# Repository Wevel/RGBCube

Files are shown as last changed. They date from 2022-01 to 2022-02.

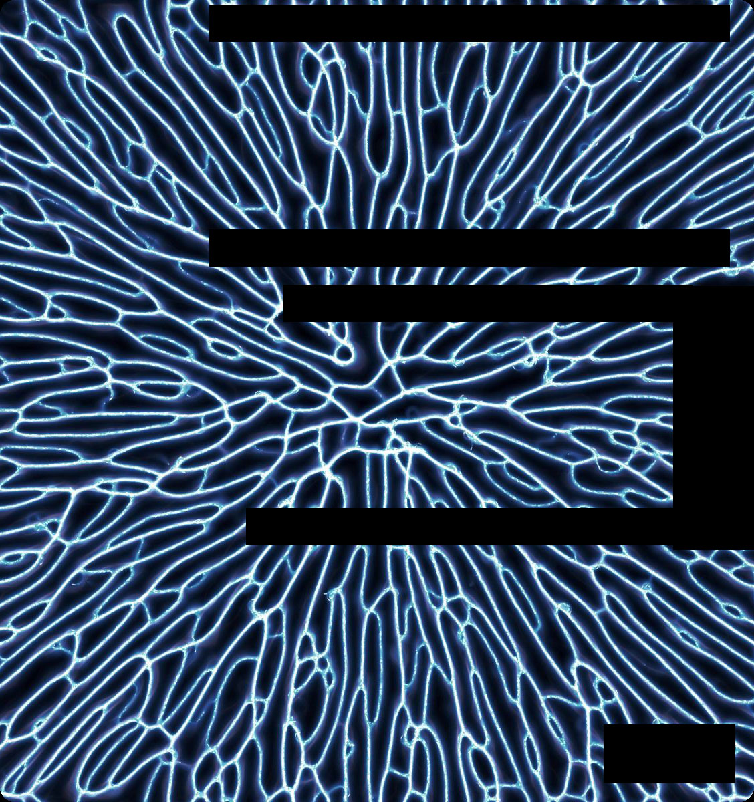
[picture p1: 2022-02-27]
Hardware/Controller/r0.1/RGBCubeController/SilkscreenPatterns/slimeMold-0.jpg

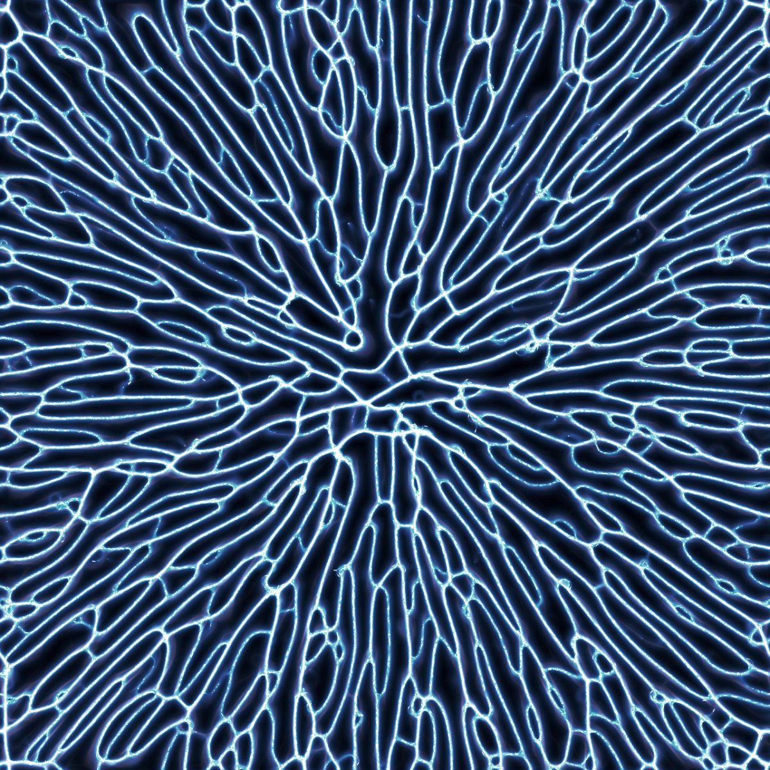
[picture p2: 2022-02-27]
Hardware/Controller/r0.1/RGBCubeController/SilkscreenPatterns/ch3_1801_slimeMold_04-1200x1200-.jpg

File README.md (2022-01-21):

# RGBCube
Project aiming to create a small led cube similar to that of [Greg Davill](https://gregdavill.com/blog/2020/6/13/miniature-3456x-led-cube). This will likely use the same [LED panels](https://github.com/gregdavill/GlassUnicorn/tree/master/hardware/panel_r0.1), but will require a new control board to account for what components are available.

## Control Board
* Change MCU to ESP32 module so as to add wifi connectivity and simplify PCB
* Change FPGA to use one of the following:
	* [Teensy 4.0](https://www.pjrc.com/store/teensy40.html): Not an FPGA, but probably still powerful enough
	* [iCEBreaker Bitsy](https://1bitsquared.com/products/icebreaker-bitsy): Not currently available, but uses the same footprint as the Teensy 4.0, so could be a future upgrade
	* [UPduino v3.1](https://tinyvision.ai/products/upduino-v3-0): May be too long
* Change IMU (Hopefully to the BNO055 if it is ever available again)

## Led Panel
This will likely use the same [LED panels](https://github.com/gregdavill/GlassUnicorn/tree/master/hardware/panel_r0.1) as Greg Davill.

## Frame
May try to 3d print something.

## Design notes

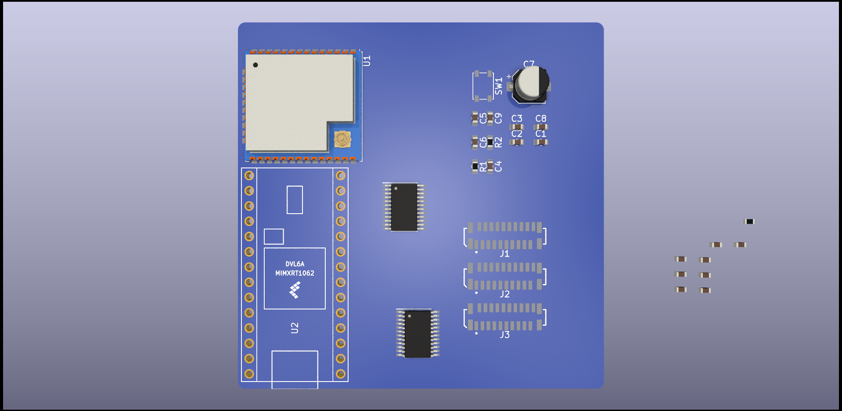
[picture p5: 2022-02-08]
Hardware/Controller/r0.1/RGBCubeController/RGBCubeController.png

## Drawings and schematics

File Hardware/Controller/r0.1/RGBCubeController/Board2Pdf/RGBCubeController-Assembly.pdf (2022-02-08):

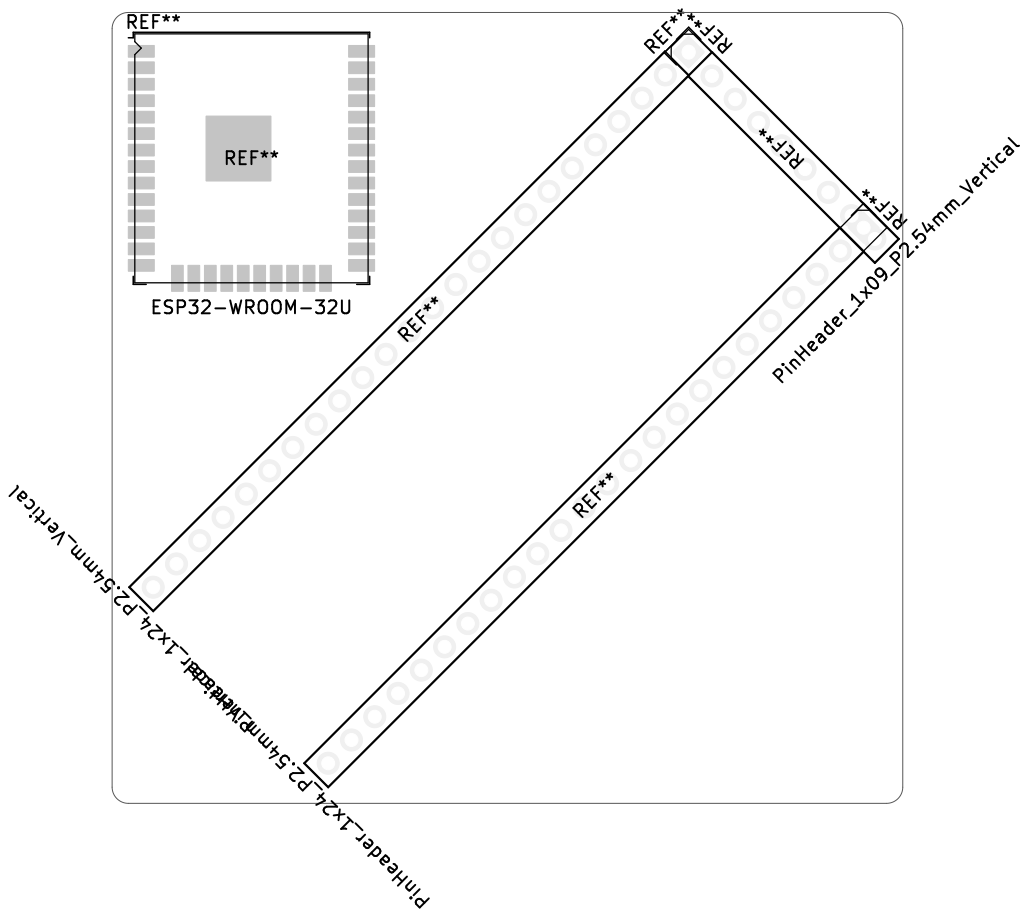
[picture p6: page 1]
REF**; REF** REF**; REF** 1 2 3 4 5 6; D Date: KiCad E.D.A. kicad (6.99.0-459-g8fe16690b7) Size: A4; Rev:; Id: 1/1 Title:; File: RGBCubeController.kicad_pcb; Sheet: Assembly; ESP32-WROOM-32U; PinHeader_1x09_P2.54mm_Vertical REF**; PinHeader_1x24_P2.54mm_Vertical

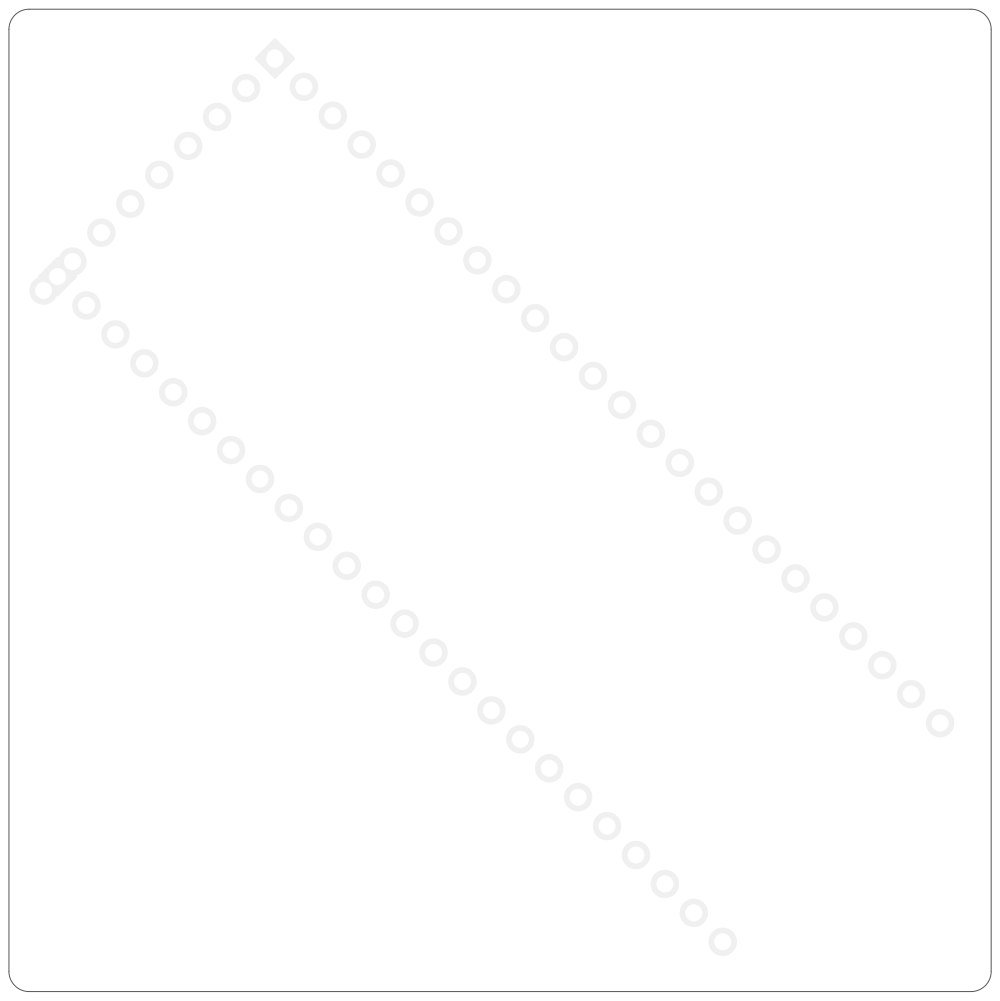
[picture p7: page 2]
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

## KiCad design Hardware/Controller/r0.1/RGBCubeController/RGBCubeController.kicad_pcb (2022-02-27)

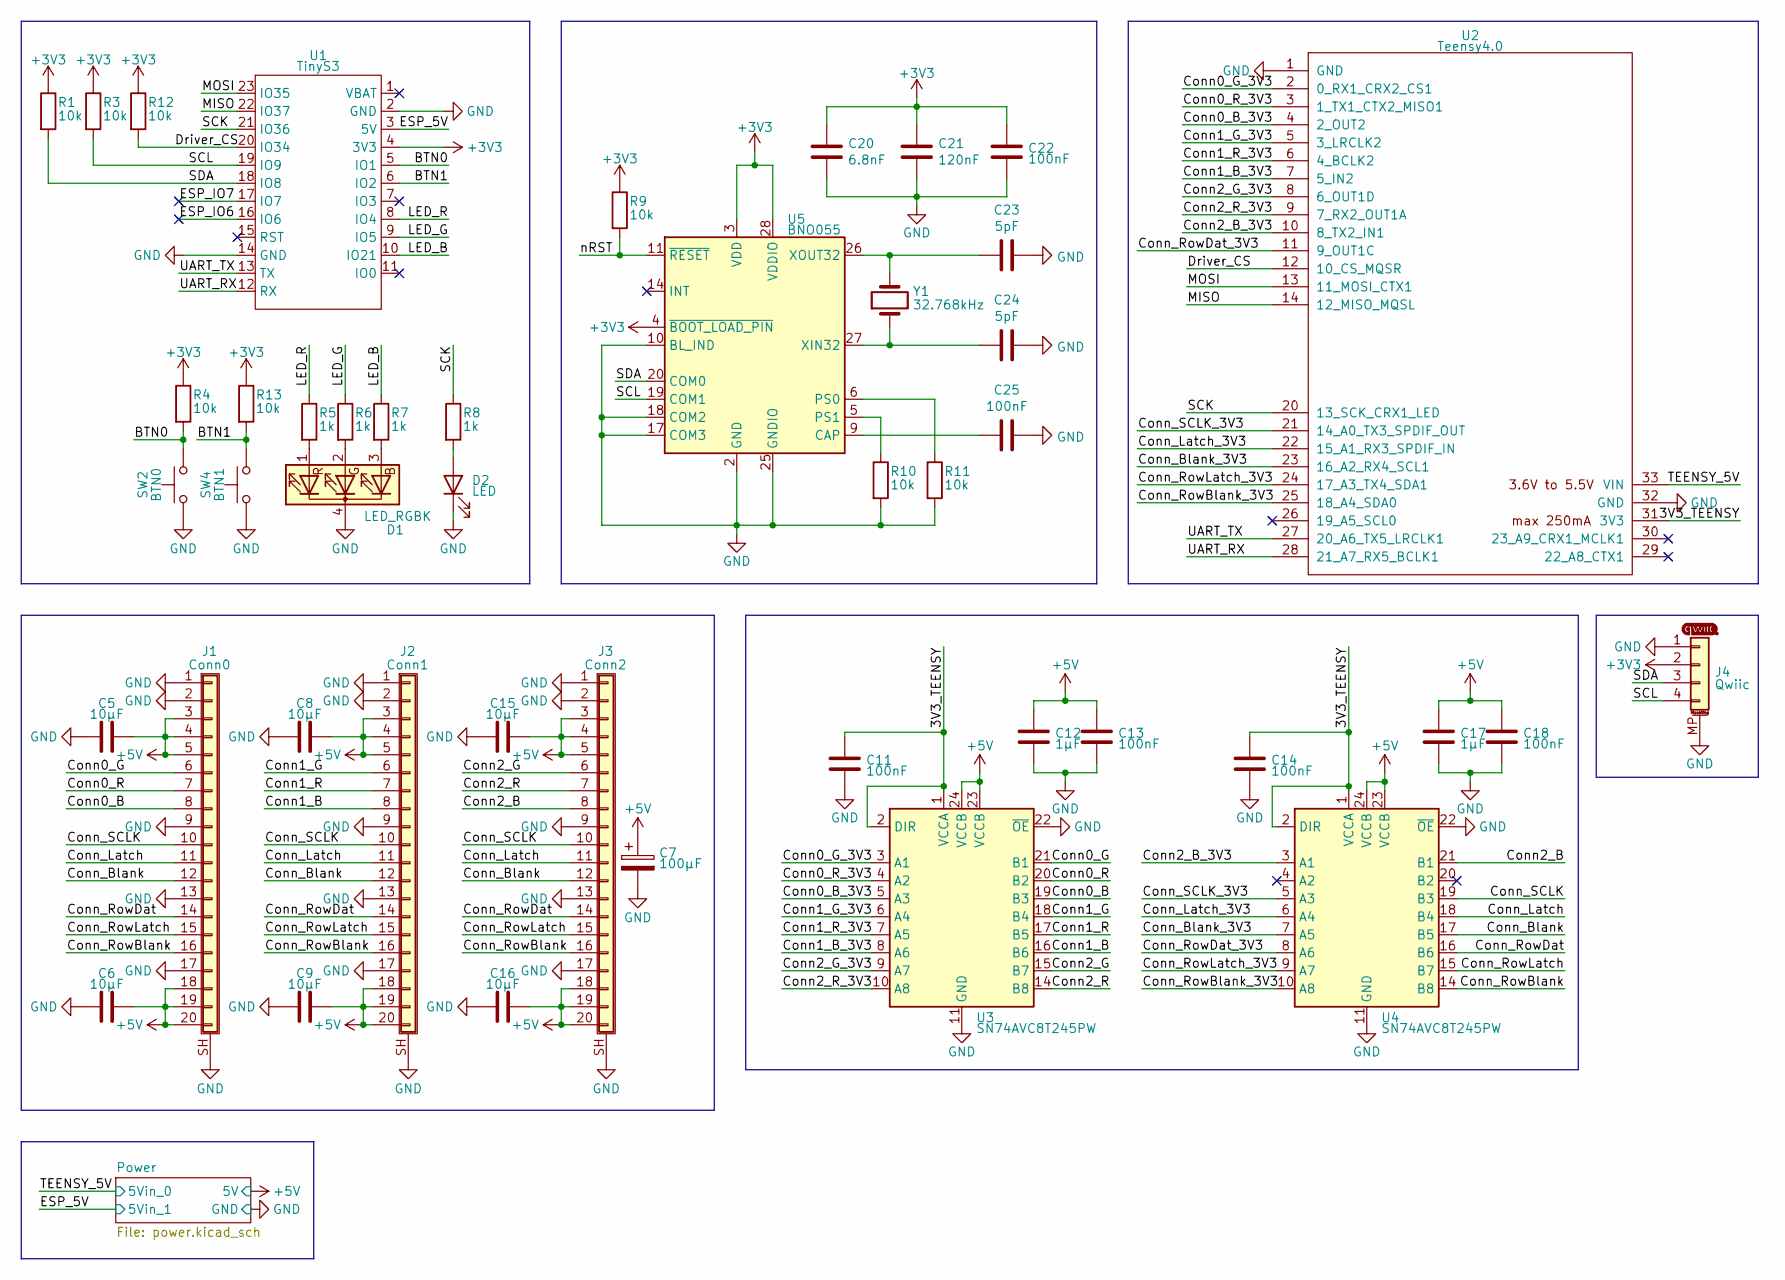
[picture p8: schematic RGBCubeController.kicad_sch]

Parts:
C5, C6, C8, C9, C15, C16: 10μF; C_0603_1608Metric
C7: 100μF; CP_Elec_5x3.9
C11, C13, C14, C18, C22, C25: 100nF; C_0603_1608Metric
C12, C17: 1μF; C_0603_1608Metric
C20: 6.8nF; C_0603_1608Metric
C21: 120nF; C_0603_1608Metric
C23, C24: 5pF; C_0402_1005Metric
D1: LED_RGBK; LED_Kingbright_AAA3528ESGCT
D2: LED; LED_0603_1608Metric
G1: LOGO; Qwiic
J1: Conn0; HRS_FH12-20S-0.5SVA(54)
J2: Conn1; HRS_FH12-20S-0.5SVA(54)
J3: Conn2; HRS_FH12-20S-0.5SVA(54)
J4: Qwiic; JST_SH_SM04B-SRSS-TB_1x04-1MP_P1.00mm_Horizontal
R1, R3, R4, R9, R10, R11, R12, R13: 10k; R_0603_1608Metric
R5, R6, R7, R8: 1k; R_0603_1608Metric
SW2: BTN0; PTS841_GKP
SW4: BTN1; PTS841_GKP
U1: TinyS3
U2: Teensy4.0; Teensy40_EdgesOnly
U3, U4: SN74AVC8T245PW; TSSOP-24_4.4x7.8mm_P0.65mm
U5: BNO055; LGA-28_5.2x3.8mm_P0.5mm
Y1: 32.768kHz; Crystal_SMD_3215-2Pin_3.2x1.5mm

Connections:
+3V3: C20.1, C21.1, C22.1, J4.2, R1.1, R3.1, R4.1, R9.1, R12.1, R13.1, U1.4 (3V3), U5.3 (VDD), U5.4 (~BOOT_LOAD_PIN), U5.28 (VDDIO)
+5V: C5.2, C6.2, C7.1, C8.2, C9.2, C12.2, C13.1, C15.2, C16.2, C17.2, C18.1, J1.3, J1.4, J1.5, J1.18, J1.19, J1.20, J2.3, J2.4, J2.5, J2.18, J2.19, J2.20, J3.3, J3.4, J3.5, J3.18, J3.19, J3.20, U3.23 (VCCB), U3.24 (VCCB), U4.23 (VCCB), U4.24 (VCCB); also elsewhere on the board
/3V3_TEENSY: C11.1, C14.1, U2.31 (3V3), U3.1 (VCCA), U3.2 (DIR), U4.1 (VCCA), U4.2 (DIR)
/BTN0: R4.2, SW2.2, U1.5 (IO1)
/BTN1: R13.2, SW4.2, U1.6 (IO2)
/Conn0_B: J1.8, U3.19 (B3)
/Conn0_B_3V3: U2.4 (2_OUT2), U3.5 (A3)
/Conn0_G: J1.6, U3.21 (B1)
/Conn0_G_3V3: U2.2 (0_RX1_CRX2_CS1), U3.3 (A1)
/Conn0_R: J1.7, U3.20 (B2)
/Conn0_R_3V3: U2.3 (1_TX1_CTX2_MISO1), U3.4 (A2)
/Conn1_B: J2.8, U3.16 (B6)
/Conn1_B_3V3: U2.7 (5_IN2), U3.8 (A6)
/Conn1_G: J2.6, U3.18 (B4)
/Conn1_G_3V3: U2.5 (3_LRCLK2), U3.6 (A4)
/Conn1_R: J2.7, U3.17 (B5)
/Conn1_R_3V3: U2.6 (4_BCLK2), U3.7 (A5)
/Conn2_B: J3.8, U4.21 (B1)
/Conn2_B_3V3: U2.10 (8_TX2_IN1), U4.3 (A1)
/Conn2_G: J3.6, U3.15 (B7)
/Conn2_G_3V3: U2.8 (6_OUT1D), U3.9 (A7)
/Conn2_R: J3.7, U3.14 (B8)
/Conn2_R_3V3: U2.9 (7_RX2_OUT1A), U3.10 (A8)
/Conn_Blank: J1.12, J2.12, J3.12, U4.17 (B5)
/Conn_Blank_3V3: U2.23 (16_A2_RX4_SCL1), U4.7 (A5)
/Conn_Latch: J1.11, J2.11, J3.11, U4.18 (B4)
/Conn_Latch_3V3: U2.22 (15_A1_RX3_SPDIF_IN), U4.6 (A4)
/Conn_RowBlank: J1.16, J2.16, J3.16, U4.14 (B8)
/Conn_RowBlank_3V3: U2.25 (18_A4_SDA0), U4.10 (A8)
/Conn_RowDat: J1.14, J2.14, J3.14, U4.16 (B6)
/Conn_RowDat_3V3: U2.11 (9_OUT1C), U4.8 (A6)
/Conn_RowLatch: J1.15, J2.15, J3.15, U4.15 (B7)
/Conn_RowLatch_3V3: U2.24 (17_A3_TX4_SDA1), U4.9 (A7)
/Conn_SCLK: J1.10, J2.10, J3.10, U4.19 (B3)
/Conn_SCLK_3V3: U2.21 (14_A0_TX3_SPDIF_OUT), U4.5 (A3)
/Driver_CS: R12.2, U1.20 (IO34), U2.12 (10_CS_MQSR)
/ESP_5V: U1.3 (5V); also elsewhere on the board
/ESP_IO6: U1.16 (IO6)
/ESP_IO7: U1.17 (IO7)
/LED_B: R7.1, U1.10 (IO21)
/LED_G: R6.1, U1.9 (IO5)
/LED_R: R5.1, U1.8 (IO4)
/MISO: U1.22 (IO37), U2.14 (12_MISO_MQSL)
/MOSI: U1.23 (IO35), U2.13 (11_MOSI_CTX1)
/SCK: R8.1, U1.21 (IO36), U2.20 (13_SCK_CRX1_LED)
/SCL: J4.4, R3.2, U1.19 (IO9), U5.19 (COM1)
/SDA: J4.3, R1.2, U1.18 (IO8), U5.20 (COM0)
/TEENSY_5V: U2.33 (VIN); also elsewhere on the board
/UART_RX: U1.12 (RX), U2.28 (21_A7_RX5_BCLK1)
/UART_TX: U1.13 (TX), U2.27 (20_A6_TX5_LRCLK1)
/nRST: R9.2, U5.11 (~RESET)
GND: C5.1, C6.1, C7.2, C8.1, C9.1, C11.2, C12.1, C13.2, C14.2, C15.1, C16.1, C17.1, C18.2, C20.2, C21.2, C22.2, C23.2, C24.2, C25.2, D1.4 (K), D2.1 (K), J1.1, J1.2, J1.9, J1.13, J1.17, J1.SH (Shield), J2.1, J2.2, J2.9, J2.13, J2.17, J2.SH (Shield), J3.1, J3.2, J3.9, J3.13, J3.17, J3.SH (Shield), J4.1, J4.MP (MountPin), R10.2, R11.2, SW2.1, SW4.1, U1.2 (GND), U1.14 (GND), U2.1 (GND), U2.32 (GND), U3.11 (GND), U3.12 (GND), U3.13 (GND), U3.22 (~OE), U4.11 (GND), U4.12 (GND), U4.13 (GND), U4.22 (~OE), U5.2 (GND), U5.10 (BL_IND), U5.15 (GNDIO), U5.16 (GNDIO), U5.17 (COM3), U5.18 (COM2), U5.25 (GNDIO); also elsewhere on the board
unnamed: D1.3 (BA), R7.2
unnamed: D1.2 (GA), R6.2
unnamed: D1.1 (RA), R5.2
unnamed: D2.2 (A), R8.2
unnamed: C25.1, U5.9 (CAP)
unnamed: R11.1, U5.6 (PS0)
unnamed: R10.1, U5.5 (PS1)
unnamed: C24.1, U5.27 (XIN32), Y1.1
unnamed: C23.1, U5.26 (XOUT32), Y1.2

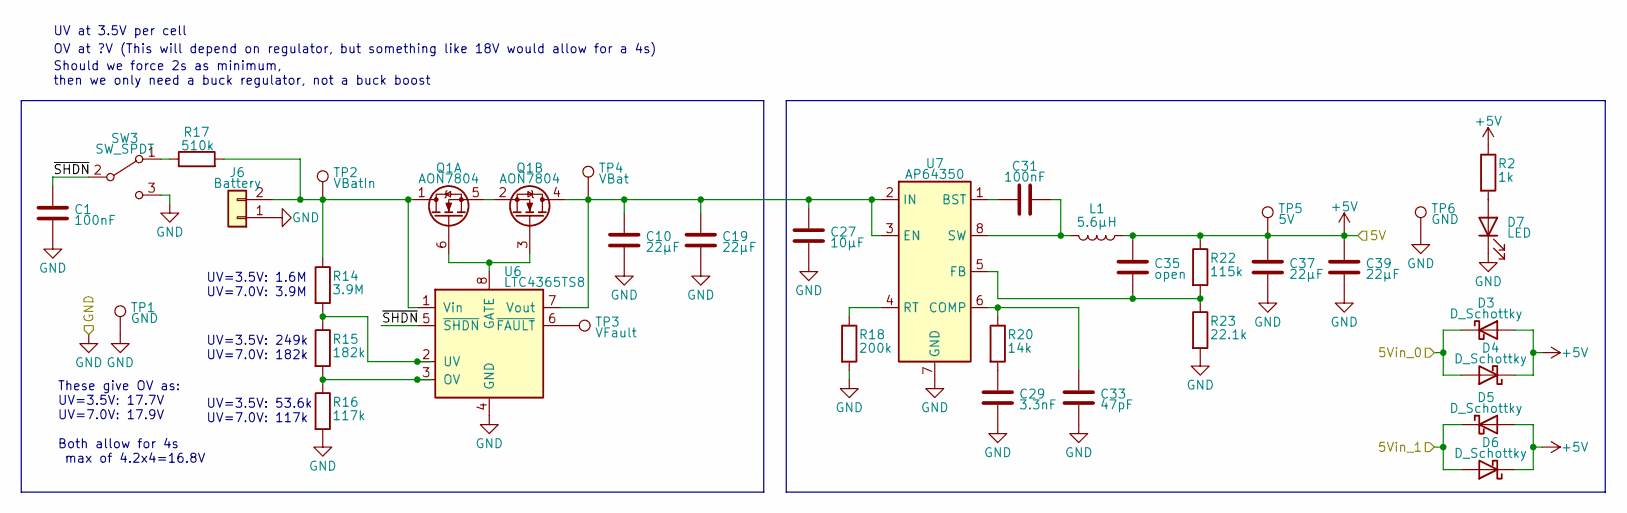
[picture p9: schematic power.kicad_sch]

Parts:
C1, C31: 100nF; C_0603_1608Metric
C10, C19, C37, C39: 22μF; C_0603_1608Metric
C27: 10μF; C_0603_1608Metric
C29: 3.3nF; C_0603_1608Metric
C33: 47pF; C_0603_1608Metric
C35: open; C_0603_1608Metric
D3, D4, D5, D6: D_Schottky; D_SOD-123F
D7: LED; LED_0603_1608Metric
J6: Battery; AMASS_XT30UPB-M_1x02_P5.0mm_Vertical
L1: 5.6μH; L_Bourns_SRN8040TA
Q1: AON7804; DFN3X3
R2: 1k; R_0603_1608Metric
R14: 3.9M; R_0603_1608Metric
R15: 182k; R_0603_1608Metric
R16: 117k; R_0603_1608Metric
R17: 510k; R_0603_1608Metric
R18: 200k; R_0603_1608Metric
R20: 14k; R_0603_1608Metric
R22: 115k; R_0603_1608Metric
R23: 22.1k; R_0603_1608Metric
SW3: SW_SPDT; SW_SPDT_PCM12
TP1, TP6: GND; TestPoint_Pad_D1.0mm
TP2: VBatIn; TestPoint_Pad_D1.0mm
TP3: VFault; TestPoint_Pad_D1.0mm
TP4: VBat; TestPoint_Pad_D1.0mm
TP5: 5V; TestPoint_Pad_D1.0mm
U6: LTC4365TS8; TSOT-23-8
U7: AP64350; Diodes_SO-8EP

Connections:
+5V: C35.1, C37.1, C39.1, D3.2 (A), D4.1 (K), D5.2 (A), D6.1 (K), L1.1, R2.1, R22.1, TP5.1; also elsewhere on the board
/ESP_5V: D5.1 (K), D6.2 (A); also elsewhere on the board
/Power/~SHDN: C1.2, SW3.2 (B), U6.5 (~SHDN)
/TEENSY_5V: D3.1 (K), D4.2 (A); also elsewhere on the board
GND: C1.1, C10.2, C19.2, C27.2, C29.2, C33.2, C37.2, C39.2, D7.1 (K), J6.1, R16.2, R18.2, R23.2, SW3.3 (C), TP1.1, TP6.1, U6.4 (GND), U7.7 (GND), U7.9 (EP); also elsewhere on the board
unnamed: C29.1, R20.2
unnamed: D7.2 (A), R2.2
unnamed: J6.2, Q1.1 (D), R14.1, R17.2, TP2.1, U6.1 (Vin)
unnamed: Q1.3 (G), Q1.6 (G), U6.8 (GATE)
unnamed: Q1.2 (S), Q1.5 (S)
unnamed: C10.1, C19.1, C27.1, Q1.4 (D), TP4.1, U6.7 (Vout), U7.2 (IN), U7.3 (EN)
unnamed: R17.1, SW3.1 (A)
unnamed: R15.2, R16.1, U6.3 (OV)
unnamed: R14.2, R15.1, U6.2 (UV)
unnamed: TP3.1, U6.6 (~FAULT)
unnamed: C31.1, U7.1 (BST)
unnamed: C33.1, R20.1, U7.6 (COMP)
unnamed: C35.2, R22.2, R23.1, U7.5 (FB)
unnamed: R18.1, U7.4 (RT)
unnamed: C31.2, L1.2, U7.8 (SW)

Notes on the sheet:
Should we force 2s as minimum, then we only need a buck regulator, not a buck boost
UV=3.5V: 1.6M UV=7.0V: 3.9M
UV=3.5V: 53.6k UV=7.0V: 117k
OV at ?V (This will depend on regulator, but something like 18V would allow for a 4s)
These give OV as: UV=3.5V: 17.7V UV=7.0V: 17.9V Both allow for 4s max of 4.2x4=16.8V
UV at 3.5V per cell
UV=3.5V: 249k UV=7.0V: 182k

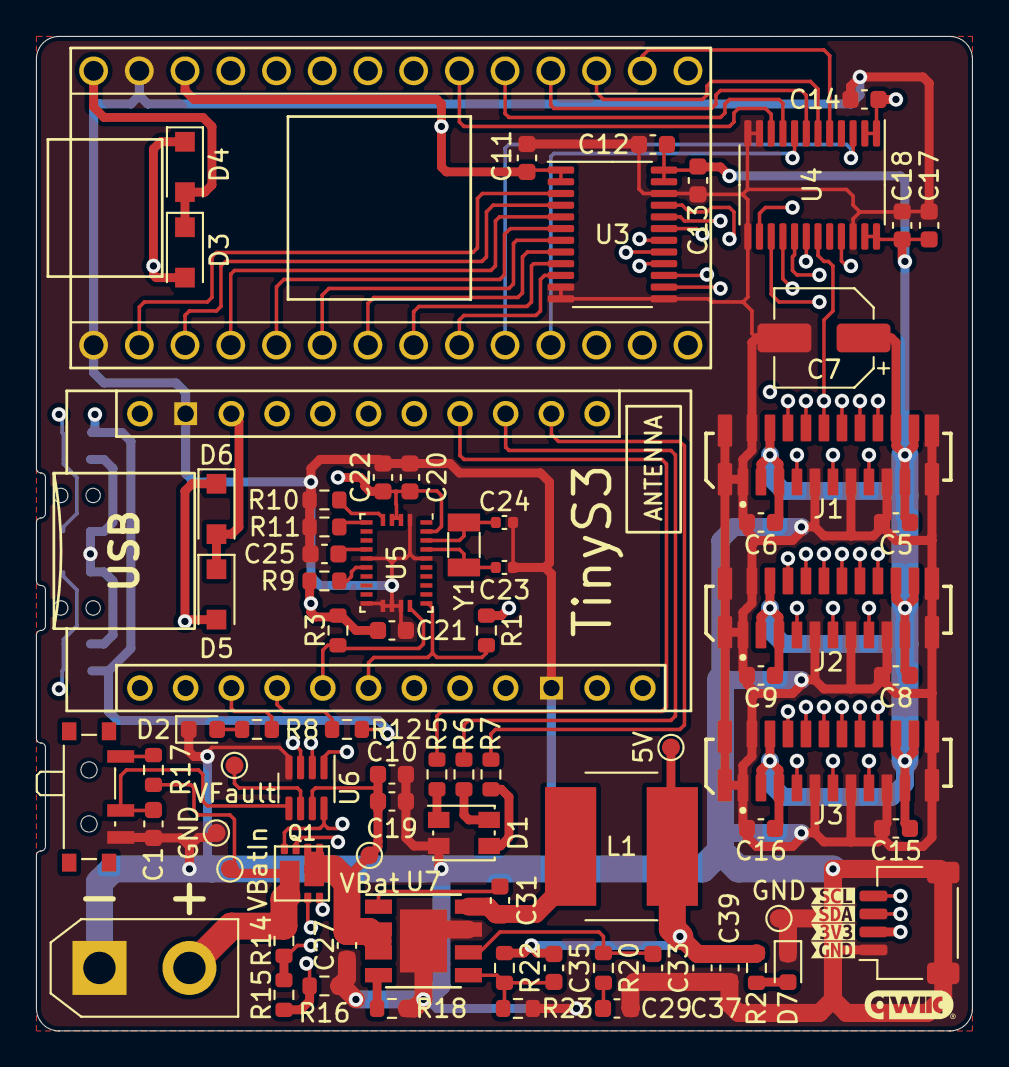
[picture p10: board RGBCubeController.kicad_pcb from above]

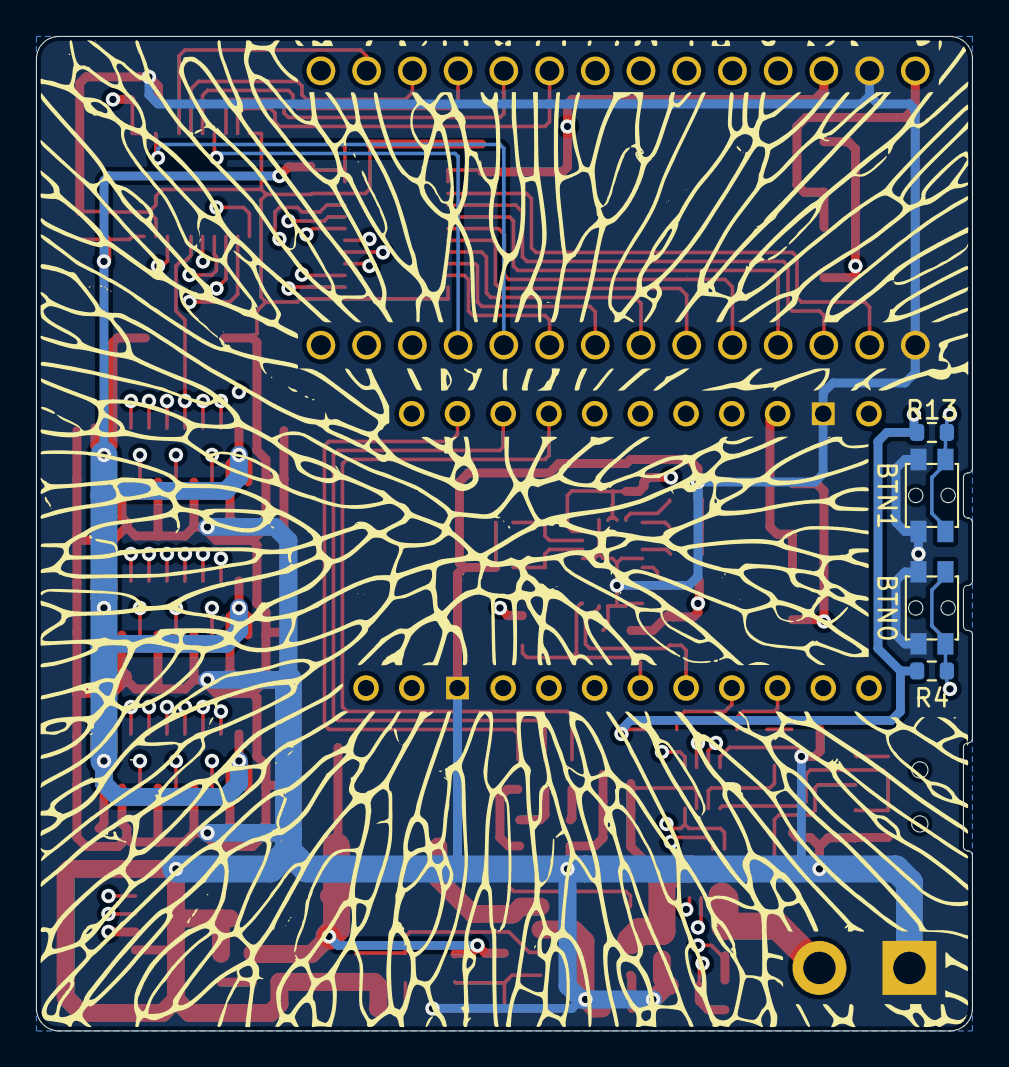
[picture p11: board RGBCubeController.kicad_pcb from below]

Board: 4 copper layers, 52.0 x 55.3 mm, 86 parts (4 on the bottom side), 75 nets.

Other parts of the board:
kibuzzard-621A4C97: G***; kibuzzard-621A4C97
kibuzzard-621A49AA: G***; kibuzzard-621A49AA
kibuzzard-621A49B5: G***; kibuzzard-621A49B5
kibuzzard-621A4989: G***; kibuzzard-621A4989

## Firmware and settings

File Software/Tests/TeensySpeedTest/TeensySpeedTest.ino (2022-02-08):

#ifndef TRUE
#define TRUE 1
#endif // !TRUE

#ifndef FALSE
#define FALSE 0
#endif // !FALSE

#ifndef NULL
#define NULL 0
#endif // !NULL

#ifdef VSCODE
#include <WProgram.h>
#endif

#include <TimeLib.h>

#include <avr/pgmspace.h>
#include <math.h>
#include <stdint.h>
#include <usb_serial.h>

#define TEST_PIN 14
#define PANEL_COUNT 6
#define NUM_CHAINS 3
#define CHAIN_PANEL_COUNT (PANEL_COUNT / NUM_CHAINS)
#define PANEL_WDITH 32
#define PANEL_HEIGHT 24
#define CHAIN_WIDTH (CHAIN_PANEL_COUNT * PANEL_WDITH * 3)
#define REPEATS 512

uint32_t lastTime = 0;
uint32_t value = 0;

void setup ()
{
	Serial.begin (115200);
	while (!Serial) {}

	pinMode (TEST_PIN, OUTPUT);
}

void loop ()
{
	uint32_t startTime = micros ();
	uint32_t tmp;

	for (uint32_t k = 0; k < REPEATS; k++)
	{
		for (uint32_t j = 0; j < PANEL_HEIGHT; j++)
		{
			for (uint32_t i = 0; i < CHAIN_WIDTH; i++)
			{
				tmp = value + i + j;
				digitalWriteFast (2, ((tmp + 0) & 0x01) != 0 ? HIGH : LOW);
				digitalWriteFast (3, ((tmp + 1) & 0x02) != 0 ? HIGH : LOW);
				digitalWriteFast (4, ((tmp + 2) & 0x04) != 0 ? HIGH : LOW);
#if NUM_CHAINS >= 2
				digitalWriteFast (5, ((tmp + 3) & 0x08) != 0 ? HIGH : LOW);
				digitalWriteFast (6, ((tmp + 4) & 0x10) != 0 ? HIGH : LOW);
				digitalWriteFast (7, ((tmp + 5) & 0x20) != 0 ? HIGH : LOW);
#endif
#if NUM_CHAINS >= 3
				digitalWriteFast (21, ((tmp + 3) & 0x08) != 0 ? HIGH : LOW);
				digitalWriteFast (22, ((tmp + 4) & 0x10) != 0 ? HIGH : LOW);
				digitalWriteFast (23, ((tmp + 5) & 0x20) != 0 ? HIGH : LOW);
#endif

				if (i >= CHAIN_WIDTH - PANEL_HEIGHT)
					digitalWriteFast (8, LOW);
				else
					digitalWriteFast (8, ((j >> (i - (CHAIN_WIDTH - PANEL_HEIGHT))) & 0x01) != 0 ? HIGH : LOW);

				digitalWriteFast (TEST_PIN, HIGH);
				delayNanoseconds (15); // Delay needs to be more than 15ns. Not sure how accurate this is for such a short delay, so this delay may actually be more
				digitalWriteFast (TEST_PIN, LOW);
				// Don't need to delay, as there will be enough other code before we set the pixel clock high again
			}
		}
	}

	uint32_t endTime = micros ();

	Serial.print ("Pixel clock: ");
	Serial.print ((1.0 / ((endTime - startTime) / (float)REPEATS)) * CHAIN_WIDTH * PANEL_HEIGHT);
	Serial.println ("MHz");
	Serial.print ("Update rate: ");
	Serial.print (1000000.0 / ((endTime - startTime) / (float)REPEATS));
	Serial.println ("Hz");

	Serial.print ("Single update time: ");
	Serial.print (1000 * ((endTime - startTime) / (float)REPEATS) / CHAIN_WIDTH / PANEL_HEIGHT);
	Serial.println ("ns");

	value++;
}

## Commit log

2022-02-08 [RGBCubeController] Completed schematic, and started on PCB.
    [RGBCubeController.kicad_pcb, RGBCubeController.kicad_sch, power.kicad_sch]
2022-02-08 [RGBCubeController] Switched to using the Unexpected Maker TinyS3 ESP32 S3 dev board. This removes the need for a 3V3 regulator, reduces the number of components, as well as improving the main microc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
    [RGBCubeController.kicad_pcb, RGBCubeController.kicad_sch, power.kicad_sch]
2022-02-09 [RGBCubeController] Added power off switch. There will still be ~10 - 20uA current draw when off, so battery should be disconnected for long term storage. Still need to route everything.
    [RGBCubeController.kicad_pcb, RGBCubeController.kicad_sch, power.kicad_sch]
2022-02-27 [RGBCubeController] Added Qwiic connector, as well as a pattern to the silkscreen on backside of PCB.
    [RGBCubeController.kicad_pcb, RGBCubeController.kicad_sch, power.kicad_sch]
